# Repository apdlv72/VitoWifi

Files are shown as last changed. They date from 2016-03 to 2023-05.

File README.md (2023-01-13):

Update 2023-01-11: Added support to pull desired ventilation level from external web site. Added support for sending notification via web API.  Fixed also some bugs.

Arduino sketch for a ESP-8266 WiFi micro controller to control a Vitovent 300 
home ventilation unit via a OpenTherm Gateway and a WiFi connection.

Vitovent is a registered trademark held by the German manufacturer Viessman.
It is a device used for automatic home ventilation with heat recovery.
For more detail please check the manufacturer's page:
http://www.viessmann.de/de/wohngebaeude/wohnungslueftung/zentrale_wohnungslueftung/vitovent-300-w.html

The actual ventilation unit is communicating with the remote controller via a 
2-wire cable connection using the OpenTherm protocol. 
Since the controller has only very limited capabilities, I wanted more control 
over when to start/stop ventilation and at what throughput.
In particular, I wanted to adjust the fan stage automatically depending on the
air and weather conditions. For example, I want the fan to run at max speed only
if this is really necessary (CO2 level too high), wanted to stop it at summer 
time when it's already hot outside and still cool inside, run at higher levels
during the cool night hours or after a rain shower.    

The ESP does not communicate with the Vitovent directly. It needs a gateway that  
converts the voltage levels and protocol used between the controller and the unit
on the one hand and the ESP on the other hand via UART (RS232 with 3.3V voltage)
This gateway was designed by Schelte Bron (see http://otgw.tclcode.com) and is
called OTGW (OpenTherm Gateway).

The general setup looks as follows:

<pre>
[Controller] <-----OT-----> [OTGW] <------OT------> [VitoVent]
                               ^
                               | RS232 (* see WARNING2 below)      
                               |     
[WebBrowser] <----WiFi----> [ESP8666]  
</pre>

Using this sketch will allow you to collect the information that was intercepted by 
OTGW and to display it on any (mobile oder desktop) browser.
 
It will also allow to control the ventilation level resp. start/stop ventilation.
Provided you create a rule for this on your router, you could even control the unit
over the internet.

Besides reading and parsing the messages from the OTGW, the sketch implements also
reading the temperature of some DS18B290 temperature sensors attached to GPIO2 of the
ESP8266. This allows to monitor the temperature at the four air connections of the
unit (supply in/outlet & exhaust in/outlet). Although the VitoVent provides its own
measures for this, it does so however only on the inlet side (at least mine).  
 
<b>WARNING 1:</b> There is absolutely no access control implemented. Doing so means that 
virtually everybody can control your unit. You should assert a security policy 
by some other means then, e.g. with a web server that implements access restrictions
before proxying the request to the ESP running this sketch.

<b>WARNING 2:</b> The ESP is powered by 3.3V while the OTGW needs 5V. Also the logic levels
on the I/O pins are 0/3.3V and 0/5V. While some people say that the ESP is not 5V
tolerant, some say that this is a myth since the datasheets states that there is some
electronics to protect agains over voltage.
It's up to you to find out who is right and to risk to brick a ESP. 
For safe operation it is recommended to use a logic level shifter such as he AN10441 or 
PCA9306 or at least to use a voltage divider on the EPS's RX pin.

Note that the cables need to be crossed thus connecting Rx on the ESP side to Tx on the
gateway and vice versa.

GPIO0 - which is used during flashing the ESP (must be pulled to ground) - can be
connected to a LED and a resistor (approx. 200-30Ohms) towards Vcc (3.3V). 
It will be used as a heart beat to indicate this sketch is still operating and also
show the current fan speed by flashing at different speeds.   

GPIO2 can be used to attach one ore more temperature sensors. A 4k7 pullup must be
used between this pin and Vcc in this case:

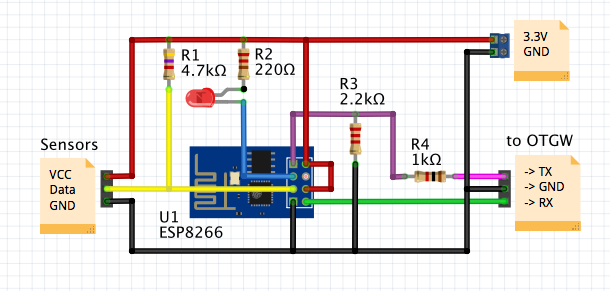
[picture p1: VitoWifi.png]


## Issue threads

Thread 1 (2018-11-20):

DIffferent Versions of Vitovent 300W

challo2018, 2018-11-20:
Hi, can someone give me datails about exact version of working 300w?
It seems that OpenTherm is not activated on mine :-(
Is it necessary to have the control panel connected on OT? Actually i have no control panel connected due the vitovent is connected to my Vitocal via Modbus.
Can you also give me hint (Art. Number etc) of your controll panel if this is necessary. Is it LB1?

Thanks!
BR Fabian

apdlv72, 2018-11-20:
Hi Fabian.

I am German, feel free to reply in German if you are capable of speaking it.

I have no idea what different versions Viessman produced in the past and I found
by incident that mine (built 2009) is OpenTherm-enabled when I opened the
remote control and stumbled over a small “OT” printed next to the screw terminator
that connects to the 2-wire line.

Also, I don't know the exact manufacturer code but it’s the same depicted here:
https://www.heizsystemshop.de/lueftungen/fernbedienung-vitovent-300.html

I don’t know if it’s possible to connect this kind of controller to YOUR Vitovent,
but I am wondering why you would like to do so???

Actually the VitoWifi project aims at connecting “somehow” to a Vitovent which
does not provide such connectivity out of the box.

When your’s has Modus already … why don’t you use that?
What exactly are you trying to achieve?

Greetings from Cologne.

Artur Pogoda de la Vega
apdlv72@gmail.com

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

challo2018, 2018-11-20:
Hi Artur,
danke für deine Antwort. Meine Vitovent 300W ist aus dem Jahr 2017.
Von meinem Heizungsbauer wurde empfohlen diese über Modbus mit der Steuerung meiner Wärmepumpe zu verbinden. Jetzt kann ich an der Wärmepumpe auch die Lüftung steuern. Eine Einbindung in mein Loxone smarthome ist allerdings nicht möglich. werder bei der wärmepumpe noch bei der lüftung. für die Wärmepume gibt es für ca. 1000€ ein KNX gateway. Damit kann allerdings nicht auf die Lüftung zugegriffen werden. Ich habe ein OTGW hier liegen und die Platine hat auch weiterhin diesen 2 Draht anschluss. Allerdings ist dieser nicht mehr mit OT sondern mit "Bedienteil (2-poliger Stecker, Adern vertauschbar,X1.1/X1.2) beschrieben. Ich habe dieses Bedienteil leider nicht. Wenn ich dort den OTGW anschließe bekomme ich keine Daten. Für eine direkte Ansteuerung über Modbus habe ich bisher noch keine Dokumentation oder ähnlich gefunden.
"

apdlv72, 2018-11-20:
Hi Fabian.

Deutsch macht die Kommunikation deutlich einfacher :-)

Kannst du Mal ein Bild der Platine schicken? Ich bin ein wenig verwirrt,
welche du meinst. Die des otgw? Oder des beckenteils? Welches du ja gar
nicht hast?

Wenn deine Wärmepumpe Modbus kann aber du noch nicht rausgefunden hast, wie
genau deine Lüftung per Modbus abgesprochen werden kann, nutzt dir
vermutlich mein Projekt wenig.

Modbus würde ich in jedem Fall vorziehen. Otgw ist nur eine Notlösung um
eine Lüftung einzubinden, die nichts anderes spricht.

Ob da trotzdem ein Signal anliegt oder nicht... Wie hast du das
rausgefunden? Weisst du, dass dein otgw funktioniert? Hast du es selbst
gelötet?

Verrat mir Mal, wo du wohnst. Ich komme aus Köln. Evtl. können wir Mal mein
definitiv funktionierendes otgw bei dir anschließen?

Gruss, Artur

Am Di., 20. Nov. 2018, 15:44 hat Artur Pogoda de la Vega <apdlv72@gmail.com>
geschrieben:

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

apdlv72, 2018-11-22:
Hallo Fabian.

Bei näherem Nachdenken ist mir klar geworden, dass Du gar keine Daten sehen KANNST,
wenn Du nur das OTGW an Deine Lueftung haengst aus folgendem Grund:

Das OTGW haengt ja im Prinzip nur zwischen dem Bedienter und dem Lueftungsgeraet und
schiebt die Befehle nur hin und her.

Die Lueftung (hier Slave) schickt von sich aus überhaupt keine Kommandos auf die Leitung sondern
beantwortet im Prinzip nur die Kommandos vom Bedienteil (hier Master).
Das einzige, was das OTGW in diesem Szenario fuer dich tun kann, ist es, den Befehl vom Master,
der die Lueftungsstufe bestimmt, so zu ersetzen, bevor es ihn weitergibt, dass die eingestellte
Luefterstufe durch eine andere ersetzt wird, die Du gerne stattdessen hättest und die Du von aussen
im OTGW setzt.

Wenn Du mir Dein OTGW schicktest, koennte ich zwar ausprobieren, ob es prinzipiell funktioniert,
damit ware Dir aber nicht weitergeholfen, weil es von sich aus nicht das Bedienteil ersetzt,
sondern wie oben beschrien nur man-in-the-middle spielt.

Da Du eine NodeMCU besitzt und anscheinend des Loetens mächtig bist, könntest Du was anderes
probieren. Ich stehe im Kontakt mit einem Nutzer, der ein ähnliches Ziel hat. Er besitzt eine Vitivent,
die definitiv OpenTherm spricht, aber er hat auch kein Bedienteil und möchte es durch einen ESP8266
ersetzen.
Er hat auch schon das Beispiel “master” aus folgendem Projekt an seiner Vitovent erfolgreich ausprobiert:
https://github.com/jpraus/arduino-opentherm/tree/master/examples/master

Allerdings nur mit einem Arduino, d.h. ohne Wifi-Anbindung.
Leider lässt sich das Beispiel nicht mit dem ESP kompilieren, weil die Initialisierung der Interrupt-Routinen
da ganz anders funktioniert. Weil er damit keine Erfahrung hatte, hat er ich um Hilfe gebeten.

Es gibt ein anderes Projekt, das  auf dem ESP kompiliert (sogar auf dem ESP-32), allerdings kann/konnte
das nicht eine Lueftung steuern, sondern nur den Thermostat fuer einen Boiler simulieren:
https://github.com/ihormelnyk/opentherm_library <https://github.com/ihormelnyk/opentherm_library>

Da ich es viel einfacher fand, Beil letzterem die nötigen Befehle/Funktionen hinzuzufügen, als das erste
Projekt zu Portieren, habe ich das getan:
https://github.com/apdlv72/opentherm_library/tree/master/examples/VentilationMaster <https://github.com/apdlv72/opentherm_library>

Allerdings ist es gänzlich ungetestet. Ich habe nur das Original-Projekt geformt und erweitert.
Im Prinzip werden die nötigen Kommandos geschickt, allerdings wird vermutlich noch Feinarbeit nötig sein.
Ich kann das leider noch nicht testen, weil ich noch auf die Interface-Platine warte. Sie ist auf dem Postweg
aus der Ukraine und das kann leider etwas dauern.
(http://ihormelnyk.com/opentherm_adapter <http://ihormelnyk.com/opentherm_adapter>)

Im Prinzip muesstest Du diese aber gar nicht haben, um zu Testen, ob deine Lueftung Kommandos
schickt oder nicht. Die Platine implementiert im Prinzip nur den Lueftings-seitigen Teil des OTGW, d.h.
kann Kommandos schickt und empfangen, nicht aber zum Bedienteil.

Wenn Du den PIC auf dem OTGW herausziehst (ist hoffentlich gesuckelt?), könntest Du Deine NodeMCU
an den entsprechenden Stellen per Dupont-Kabel einstecken und mit meinem Beispiel versuchen,
Bedienteil zu spielen, um zu sehen, ob Die Kommandos ueberhaupt beantwortet werden.
Vorausgesetzt, Du hast Dich nicht verlötet beim OTGW und Deine Lueftung spricht OT, muesstest die
im Prinzip schon Antworten sehen koennen, ohne dass Du irgendwas neu anschaffen musst.

Falls das funktioniert, kannst Du entweder das OTGW, was Du eh schon gekauft hast, statt mit dem
PIC mit dem NodeMCU betreiben oder Du kannst Dir den o.g. Opentherm Adapter bestellen oder selbst
loeten. Das sind nur wenige billige Bauteile, die schnell auf einer Lochrasterplatine zusammengelötet sind.
Da ich momentan zu wenig Zeit habe, hab ich mir das bequemerweise bei Ihor bestellt.

VG
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
arnolde, 2019-01-19:
Hallo, sorry wenn ich hier so reinplatze ;-) ich hab gerade diese Woche meine ESP mittels Ihor's Library (manuell um einige Lüftungs-Parameter ergänzt) und Ihor's OT Interface geschafft, meine WOLF CWL 300 (baugleich Vitovent) anzusteuern und auszulesen. Momentan kann ich die Lüfterstufen 0,1,2,3 schalten oder auch die rel.lüfterleistung von 20%-95% stufenlos einstellen.

Was ich noch nicht geschafft hab ist die Filteranzeige auszulesen (wobei ich jetzt hier gelesen hab daß das TSP (Id 89) Nummer 0x17 sein soll, 1 ist offenbar "filter ok", mal sehen was meiner grad sagt, bei dem ist grad die Filteranzeige an. Ausserdem den Bypass noch ansteuern (da ich einen Erdwärmetauscher hab, will ich den Bypass im Sommer aus haben um kühle Luft reinzuziehen). Und perfekt wäre wenn ich den Lüfter auch unterhalb 20% noch einstellen könnte, damit ich im Winter bei trockener Luft eine noch minimalere Lüftung haben kann.

viele Grüße,
Ethan

arnolde, 2019-01-19:
Seltsam, ich hab grad alle 64 TSP's ausgelesen und erhalte für 0,2,4: 0x64, 0x96 und 0x2c - das passt aber nicht zu den tatsächlichen Ergebnissen wenn ich die Stufen 1/2/3 aktiviere dann sind die ausgelesenen Drehzahlen: 0x24, 0x39 und 0x5f.

madmax75, 2020-04-29:
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

Hallo Ethan,
ich betreibe ebenfalls eine Wolf CWL 300 und würde diese gerne per OTGW auslesen. Ich habe ein Gateway mit NodeMCU hier bei mir liegen und habe versucht mit dieser die KWL anzubinden. Leider vergeblich. Gibt es eine Anleitung wie die genaue Vorgehensweise ist um die Verbindung herzustellen?

apdlv72, 2020-04-30:
Hallo madmax75!

Was genau hast du denn versucht und was hat nicht geklappt? Da du das Gateway ja schon fertig da liegen hast (Bausatz selbst zusammen gelötet oder fertig gekauft?), sollte das Anschließen selbst ja relativ unproblematisch sein: Kabel zur Lüftung an die eine klemme, Kabel zum Controller an die andere.

Danach muss vermutlich noch auf den PIC des otgw die aktuelle Software aufgespielt werden und anschließend auf dem mcu deine eigene Lösung oder z.B. mein vitowifi, um mit dem otgw zu kommunizieren, um den aktuellen Status verfügbar (WLAN) zu machen oder die Lüfterstufen zu beeinflussen.

VG
Artur

madmax75, 2020-05-03:
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

Hallo Artur,

> Danach muss vermutlich noch auf den PIC des otgw die aktuelle Software aufgespielt werden und anschließend auf dem mcu deine eigene Lösung oder z.B. mein vitowifi, um mit dem otgw zu kommunizieren, um den aktuellen Status verfügbar (WLAN) zu machen oder die Lüfterstufen zu beeinflussen.

Ganau hier komme ich nicht weiter. Wie bekomme ich die die aktuelle Software auf das Gateway und welche muss ich genau nehmen?
Stehe da gerade total auf dem Schlauch.

VG
Andre

madmax75, 2020-05-09:
Hallo Artur,
ich habe jetzt erfolgreich die PIC und die nodemcu flashen können und bekomme nun auch die Webseite angezeigt.
Ich habe nun noch keine Info gefunden wie ich meine FB mit dem OTGW verbinden muss(welche Klemmbelegung).

Gruss
André

gzin, 2021-03-29:
Hallo Artur!
Ich habe auch eine Wolf CWL 300 und das Gateway von Shelte Brom. Wenn ich den Ethernet-Aufsatz aufstecke, dann kann ich per serieller (Netzwerk-)Verbindung schon wunderbar mitlesen: nach dem Befehl "GW=1" schickt er zyklisch ein paar Befehle hin und bekommt Antwort. Leider wechselt die CWL immer zwischen 0 ("ferngesteuert") und 1 ("Wahlschalter"). Wenn ich dann den Befehl "GW=0" sende, ist die Anlage wieder dauerhaft im Wahlschalter-Modus. (eine inkludierte Fernsteuerung über OpenTherm habe ich nicht)
Spiele ich die Software von dir auf den NodeMCU (auf derselben Platine wie der PIC; statt dem Ethernet-Modul), dann beobachte ich dieses zyklische Umschalten zwischen 0 und 1 ebenfalls. Also nehme ich an, dass die Ansteuerung funktioniert (zumindest "GW=1").
Ich habe noch vom Betrieb über das Arduino-Terminal gesehen, dass da Befehle wie ZZ=r oder oder ZZ=wwww gesendet werden. Sollte die Firmware das können? Wenn ich mir die Befehle so ansehe, steht da nichts von "ZZ" drinnen:
http://otgw.tclcode.com/firmware.html#configuration
Verwende ich die falsche Firmware? (ich habe die aktuellste eingespielt) Ist der Befehl "ZZ" bei der neuen Firmware raus geflogen?

Alterntiv habe ich mir das Modul aus der Ukraine (http://ihormelnyk.com/opentherm_adapter) samt Adapter für Mini-D1 (8266) bestellt und bekommen. Hier komme ich aber auch nicht weiter, weil ich noch beim Programmieren hänge.

apdlv72, 2023-01-11:
No action anymore

apdlv72, 2023-01-11:
Closing

gzin, 2023-01-11:
Inzwischen läuft das Modul mit dem D1-Mini recht gut, ich kann die Lüftungsstärke steuern und auch alle Register auslesen.

Was noch nicht klappt ist die Steuerung des Bypasses und das Auslesen der Filter-Alarms. Hat da jemand eine Idee?

Gruß
Günther

Closed 2023-01-11.

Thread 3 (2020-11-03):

cant connect to ap

crazypaddo, 2020-11-03:
hello sir, i have a brink wtw ventilation unit.(same as vitovent)
i have 2 otgw interfaces,
i first used off 1 otgw only the boiler part to connect to a arduino mega as a master with the opentherm library to send commands to  the wtw unit.
this works because i can turn the unit on and off and set the relative ventilation value.
So data is flowing between the master and slave.
now i have programmed a nodemcu v3 with your project. so far so good.
i see the ssid apear when i want to connect to the network http://192.168.4.1 and i see something about tokken created in the debug terminal.
i open my webbrowser and go to http://192.168.4.1 type VitoWifi and password 12345678 and hit connect.
but when i look at the debug terminal from the esp i see error 4 and the page counts down and times out?
but the data from my arduino mega master gets true the gateway because the ventilation units stays in opentherm modus
and when i change the send data id in the master the unit changes the value.(speeds up / slows down ventilation motors).
but i am not an expert in programming and cant seem to figure out whats the problem.
could it be due to me turning aldataids on? because i got some errors in arduino while compiling about dupicated case entrys?
i commented the out,and it compiled without errors. but maybee i broke something wyle doing this.
i hope you an guide me in the write direction. so i can save a lot off monney on my heating bill that my heat provider want from me to heat a small appartment.
regards marco van oort

apdlv72, 2023-01-11:
No action. Closing

apdlv72, 2023-01-11:
Close

Closed 2023-01-11.

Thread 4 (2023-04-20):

Any known solution for connecting via modbus?

thilasx, 2023-04-20:
Hey there!
Thanks for sharing your solution for the vitovent with OT protocol.
I'd like to ask if you know a solution for reading the sensors and configuring the vent via modbus?
I searched the net yesterday but was only able to find that viessmann is most likely buying their vent solutions from another manufacturer called brink and that some people were able to use a modbus adapter but weren't able to connect successfully.
Therefore, because you mentioned in another issue that you would prefer modbus, I thought you might know a way.

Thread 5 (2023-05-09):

Fehlermeldung beim Kompilieren

madmax75, 2023-05-09:
Hi @apdlv72,
ich wollte die aktuelle Version auf meine nodemcu per Arduino IDE aufspielen, erhalte jedoch die folgende Fehlermeldung:

In file included from /Users/andre/Documents/Arduino/ESP_VitoWifi/ESP_VitoWifi.ino:175:
/Users/andre/Documents/Arduino/ESP_VitoWifi/OTMessage.h: In static member function 'static String OTMessage::msgTypeToStr(uint8_t)':
/Users/andre/Documents/Arduino/ESP_VitoWifi/OTMessage.h:48:5: error: control reaches end of non-void function [-Werror=return-type]
   48 |     }
      |     ^
cc1plus: some warnings being treated as errors

exit status 1

Compilation error: control reaches end of non-void function [-Werror=return-type]

apdlv72, 2023-05-10:
Hi.

Welche Arduino version? Ich habe das seit Dezember nicht mehr gebaut. Da
fehlt wohl ein Return in der Funktion wie zb return "" am Ende der
Funktion.

Falls du es selbst hinbekommst, mache gerne einen pull request. Ansonsten
melde dich nochmal. Ist bestimmt kein biggie.

Gruß,
Artur

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

madmax75, 2023-05-11:
Hi Artur,
ich habe es mit Arduono IDE 2.1.0 versucht und es leider mit deiner Anweisung nicht hinbekommen. Könntest du dir das netterweise mal anschauen?
LG André

madmax75, 2023-06-04:
> Hi Artur,
> ich habe es mit Arduono IDE 2.1.0 versucht und es leider mit deiner Anweisung nicht hinbekommen. Könntest du dir das netterweise mal anschauen?
> LG André

apdlv72, 2023-06-05:
Hall Andre.
Ich verstehe nicht, wie der jetztige Stand ist. Compiliert es jetzt bei Dir oder immer noch nicht?
Habe gesehen, dass Du den Request geschlossen und sofort wieder geoeffnet hast.
VG, Artur

madmax75, 2023-06-05:
Hallo @apdlv72,
leider erhalte ich beim kompilieren die oben genannte Fehlermeldung. Hatte aus Versehen den Request geschlossen.
VG
Andre

apdlv72, 2023-06-07:
Hallo Andre!
Welche Fehlermeldung? Die urspruengliche? (control reaches end of non-void function)
Hast Du denn neu gepullt nachdem ich das letzten Monat gefixt hatte?
Der aktuelle Code sieht so aus - siehe unten.
In der Zeile 48 ist jetzt vorher fehlende der Default-Rueckgabewert, ueber den sich der Compiler beschwert hat.
Wie bereits geschrieben, habe ich das _auch_ mit der Version 2.1.0. der IDE erfolgreich kompilieren koennen.
VG, Artur

37 static String msgTypeToStr(uint8_t t) {
38      switch(t) {
39        case MT_READ_DATA:    return "READ_DATA";
40        case MT_WRITE_DATA:   return "WRITE_DATA";
41        case MT_INVALID_DATA: return "INVALID_DATA";
42        case MT_RESERVED:     return "RESERVED";
43        case MT_READ_ACK:     return "READ_ACK";
44        case MT_WRITE_ACK:    return "WRITE_ACK";
45        case MT_DATA_INVALID: return "DATA_INVALID";
46        case MT_UNKN_DATAID:  return "UNKN_DATAID";
47      }
48      return "UNKNOWN";
49    }

madmax75, 2023-06-18:
Hi @apdlv72,
ich habe es nun am Laufen. Besten Dank.
Wie kann ich nach dem Setup den Access Point Modus "AP_VitoWifi" abschalten, sodass dieser nicht mehr sichtbar ist?

Gruß
Andre

apdlv72, 2023-07-03:
Hi @madmax75 !

Versuche es mal in folgender Zeile
https://github.com/apdlv72/VitoWifi/blob/master/ESP_VitoWifi.ino#L885
EE.accessPoint.used = 0 zu setzten.
Das ist aber ohne Gewaehr. Ich habe bei mir den AP Modus immer aktiviert,
um z.B. bei einem Router-Wechsel das Passwort aendern zu koennen ohne
dass ich den ESP ausbauen muss.

Du kannst auch in diese Zeile:
https://github.com/apdlv72/VitoWifi/blob/master/ESP_VitoWifi.ino#L1775
Fest den AP ausschalten mit:
WiFi.mode(WIFI_STA);

VG,
Artur

Closed 2023-08-17.

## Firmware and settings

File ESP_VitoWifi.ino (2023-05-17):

// Copy secrets.h to secrets_priv.h, same for index.html.h and comment in to 
// activate your own versions of this file. Add both files to .gitignore!!!
#define WITH_OWN_SECRETS

#ifdef WITH_OWN_SECRETS
#include "secrets_priv.h"
#else
#include "secrets.h"
#endif

/**
   Arduino sketch for a ESP-8266 WiFi micro controller to control a Vitovent 300
   home ventilation unit via a OpenTherm Gateway and a WiFi connection.
   See https://github.com/apdlv72/VitoWifi or README.md
   @author: apdlv72@gmail.com
*/

// Uncomment WITH_DALLAS_TEMP_SENSORS to enable support for DS18B290 temperature sensors connected on PIN_SENSOR.
// MAX_NUM_SENSORS defines the maximum number of sensors connected.
// Since this sketch is for a home ventilation system, actually 4 would be sufficient for inlet/outlet air supply
// and inlet/outlet exhaust. However, defining 8 here lets us add even more e.g. for monitoring the room temperature(s)
// in your basement and/or living room, monitoring the temperature inside the OTGW device and so forth.
// Every sensor requires just 2 bytes in RAM, so a large value is not too critical.
#define WITH_DALLAS_TEMP_SENSORS

#define MAX_NUM_SENSORS 6

// Uncomment to support a pin test on http://192.168.4.1/pintest?p=0.
// When called, the mode of the respective pin "p" will be set to OUTPUT and value toogled between hi/low a couple of times.
// This is useful to find out which pin number is assigned to what pin. Be careful with pins used by the ESP.
// Check https://github.com/esp8266/Arduino/issues/1219 for more details.
//#define WITH_PIN_TEST

// Uncomment to enable ID to text translation of all known OpenTherm data IDs.
// This cause a considerable overhead in RAM usage and is not enable by default since it is not used for normal operation.
// However, should you use this sketch as a starting point to control anything else than a VitoVent 300, you might enable
// this to learn what your devices are talking to eachother.
//#define WITH_ALL_DATAIDS

// enable OTA (over the air programming)
//#define WITH_OTA

// Enable serial debug functions
//#define WITH_DEBUG_SERIAL

// Enable sending debug messages on UDP port
#define WITH_DEBUG_UDP
#define UDP_PORT 4220

// Enable sending continuous stream of OT messages received on /dbg/tailf
// #define WITH_TAILF

// Enable a help page on http://192.168.4.1/help
//#define WITH_USAGE_HELP

// Enable html page to setup the device via browser.
//#define WITH_WEB_SETUP

// Enable upating ventilation level from an external web page on a regular basis.
// Also requied to send alerts using a web API.
#define WITH_WEB_CALLS

// Enable adding invalid lines (commands) being handles as errors
#define WITH_INVALID_LINES_AS_ERRORS false

const char DEFAULT_START_SSID[] = "AP_VitoWifi";

// Initial password used to connect to it and set up networking.
// The device will normally show up as SSID "http://192.168.4.1"
// Connect to this network using the intial password and navigate your
// browser to the above URL.
#define DEFAULT_PSK  "12345678"

#define HTTP_LISTEN_PORT 80

/****************************************/

#include <errno.h>
#include <EEPROM.h>

#ifdef ESP8266
#include <ESP8266WiFi.h>
#include <ESP8266WebServer.h>
#elif ESP32
#include <WiFi.h>
#include <WiFiClient.h>
#include <WebServer.h>
#else
#error Unsupported platform
#endif

#ifdef WITH_OTA
#include <ArduinoOTA.h>
#endif

#include <WiFiUdp.h>
#ifdef WITH_WEB_CALLS
#include <UrlEncode.h>
#endif

#ifdef WITH_DALLAS_TEMP_SENSORS
#include <OneWire.h>
#include <DallasTemperature.h>
#endif

// Using a copy of "easy EEPROM" library since needed to modify for ESP
// to cope with watchdog timer resets (https://github.com/apdlv72/eEEPROM)
//#include "eEEPROM.h"

const String buildNo   = __DATE__ " " __TIME__;

#define LED_HEART 	  0 // heartbeat 
#define LED_ONBOARD   2 // blue onboard LED / temp. sensors

#define LEVEL_NOOVER -1 // do not overrride (monitor mode)
#define LEVEL_OFF     0 // standby, ventilation off
#define LEVEL_LOW     1 // "reduced" mode (27% for mine ... may vary)
#define LEVEL_NORM    2 // "normal"  mode (55% for mine) 
#define LEVEL_HIGH    3 // "party"   mode (100%)

// result codes of onOTMessage
#define RC_OK         0	// message handled
#define RC_INV_LENGTH 1 // invalid message length (not Sxxxxxxxx)
#define RC_INV_FORMAT 2 // xxxxxxxx was not a parsable hex value
#define RC_INV_SOURCE 3 // S is not a known source (T,B.R,A)
#define RC_UNEXP_T    4 // unexpected message from T(hermostat)/controller/master
#define RC_UNEXP_B    5 // unexpected message from B(oiler)/ventilation/slave
#define RC_UNEXP_R    6 // unexpected request (sent by OTG in favor of master)
#define RC_UNEXP_A    7 // unexpected answer  (sent by OTG in favor of slave)
#define RC_UNEXP_O    8 // unexpected message from unknown source (should never occur) 

#define CT_TEXT_PLAIN  "text/plain"
#define CT_TEXT_HTML   "text/html"
#define CT_APPL_JSON   "application/json"

// Context type sent along with content stored in PROGMEM:
const char PGM_CT_TEXT_HTML[] PROGMEM = "text/html";
const char PGM_CT_APPL_JSON[] PROGMEM = "application/json";

#ifdef WITH_OWN_SECRETS
#pragma message "index_priv.h is active"
const char HTML_INDEX[] PROGMEM =
#include "index_priv.html.h"
  // The following line makes buildNo accessible for javascript:
  "<script>var buildNo = '" __DATE__ " " __TIME__ "';</script>";
;
#else
const char HTML_INDEX[] PROGMEM =
#include "index.html.h"
  // The following line makes buildNo accessible for javascript:
  "<script>var buildNo = '" __DATE__ " " __TIME__ "';</script>";
;
#endif

#ifdef WITH_WEB_SETUP
const char HTML_SETUP[] PROGMEM =
#include "setup.html.h"
  ;
#endif

#ifdef WITH_ICONS
const char MANIFEST_JSON[] PROGMEM =
#include "manifest.json.h"
  ;

const char FAVICON_ICO[] PROGMEM =
#include "favicon.ico.h"
  ;

const char FAN_PNG[] PROGMEM =
#include "fan.png.h"
  ;
#endif  

// Conveniently zero-terminates a C-string.
#define TZERO(STR) { (STR)[sizeof((STR))-1] = 0; }

#include "OTMessage.h"

typedef struct {
  // Use signed 16 bits to allow -1 to indicate that
  // value was not yet assigned.
  int16_t hi;
  int16_t lo;
} Value;

// Global status
struct {
  struct {
    long serial; // time of last message via serial line
#ifdef WITH_DEBUG_SERIAL
    struct {
      long fed;		// via URL /feedmsg?msg=...&feed=1
      long debug; 	// via URL /feedmsg?msg=... (parsed only, not fed)
    } wifi;
#endif
  } lastMsg;         // time (millis()) when last message was received

  int16_t  ventSetpoint; 	   // as set by controller
  int16_t  ventOverride; 	   // as overridden by OTGW (sent to slave instead of ventSetpoint)
  int16_t  ventWeb;          // received from external web resource/page (see web_update.h)
  int16_t  ventAcknowledged; // by the slave, sent to OTGW
  unsigned long lastAcknChange;

  int16_t  ventReported;     // from OTGW to controller, pretending level is as requested (ventSetpoint)
  int16_t  ventRelative; 	   // as reported by ventilation
  int16_t  tempSupply;  	   // milli Celsius (inlet)
  int16_t  tempExhaust;  	   // milli Celsius (inlet)
  int16_t  tsps[64];  	 	   // transparent slave parameters

  struct {
    Value master;
    Value slave;
  }        version;			// values for DI_*_PROD_VERS

  Value    status;
  Value    faultFlagsCode;
  Value    configMemberId;
  Value    masterConfig;
  Value    remoteParamFlags;

  struct {
    long serial;	// total number of messages received on serial line

    struct {
      long fed; 	// via /feedmsg?feed=1...
      long debug; 	// (parsed only, not fed)
    }    wifi;

    // number of invalid messages received
    struct {
      long length;		// invalid length
      long format;		// invalid line (pasing failed)
      long source;		// invalid source (not T,B,R,A)
    } invalid;

    // expected messages of various types
    struct {
      long T; long B; long R; long A;
      long otgw; // otgw message response e.g. "GW: 1" replied on "GW=1"
    } expected;

    // unexpected messages of various types
    struct {
      long T; long B; long R; long A; long zero;
    } unexpected;

  } messages; // number of messages received

  unsigned long timeAdj = 0;
  String scriptVersion;
  String scriptName;
  String filterAction;
  String cartridgeAction;

#ifdef WITH_DALLAS_TEMP_SENSORS
  int sensorsFound;
  long lastMeasure;
  int16_t extraTemps[MAX_NUM_SENSORS];
#endif

} state;

// Health monitoring and alert/report book keeping
struct {
  // time when requested and acknowleged override started to differ
  unsigned long ventDiffStarted = 0;
  // time when last report sent that there is a difference
  unsigned long lastDiffReported = 0;
  // time we sent a recovery message (device responsive again)
  unsigned long lastRecoveryReported = 0;
  // time of last OTGW reset attempt
  unsigned long lastGWReset = 0 ;
  // time of when GW reset was reported
  unsigned long lastGWResetReported = 0;

  boolean isResponsive  = true;
  boolean wasResponsive = true;

  // initial memory
  long initalFree = -1;

  // 1 hour before millis() will roll over
  unsigned long rebootTime = 4294967296 - 3600 * 1000;

  boolean startAnnounced = false;
  boolean rebootAnnounced = false;

  unsigned long lastWebCheck = 0;
  unsigned long lastWebCheckError = 0;

  unsigned long webFailCount = 0;
  unsigned long postOkCount = 0;

  String lastRebootDetails = "";

  long loopIterations = 0;
} health;


#define WEB_CHECK_INTERVAL (20*60*1000) // 20 minutes

// Credentials used to 1. set up ESP8266 as an access point and 2. define WiFI network to connect to.
typedef struct {
  uint8_t used;
  char    ssid[32 + 1];
  char    psk[32 + 1];
} Credentials;

// I'm from cologne ;)
const uint16_t MAGIC = 0x4712
;

// Everything that goes to EEPROM
struct {
  // Detect if first time setup of EEPROM was done.
  uint16_t  magic;
  boolean 	configured;
  // Start ESP in access point mode?
  Credentials accessPoint;
  // Network to connect to
  Credentials homeNetwork;
  // Count incremented on every reboot to enable monitoring of device crashes.
  uint32_t reboots;
  char     rebootDetails[128];
} EE;

// User committed first time setup (e.g. AP, network) and it was saved permanently.
boolean configured = false;

// A random token used during setup to authenticate committer.
char configToken[10 + 1];

// Time at which an attempt to connect to a network will be considered expired during setup procedure.
long connectAttemptExpires = -1;

// Remember whether temperatures have been already requested for the first time.
boolean temperaturesRequested = false;

// After setup, a reboot is necessary. However, cannot do this while handling client request,
// because this will abort the connection. Instead of this, finish sending the reponse to the
// client and schedule a reboot after millis() will exceed this value.
long rebootScheduledAfterSetup = -1;

// A string to hold incoming serial data from OTGW.
String inputString = "";
// wWhether the string is complete.
boolean stringComplete = false;

// set in setup()
unsigned long stopUdpLoggingAfter = 0;

#ifdef ESP8266
ESP8266WebServer server(HTTP_LISTEN_PORT);
#elif ESP32
WebServer server(HTTP_LISTEN_PORT);
#endif

/***************************************************************

   Heart beat LED

*/

boolean led_lit = false;
volatile boolean led_blink = false;
int timer_value = 250000;

//void ICACHE_RAM_ATTR timerRoutine() {
void IRAM_ATTR timerRoutine() {
  if (led_blink) {
    led_lit = (millis() / 50) % 2;
    digitalWrite(LED_HEART, led_lit ? LOW : HIGH);
  }
  timer1_write(timer_value);
}

void ledToggle() {
  led_lit = !led_lit;
  digitalWrite(LED_HEART, led_lit ? LOW : HIGH);
}

void ledFlash(int ms) {
  ledToggle();
  delay(ms);
  ledToggle();
}

/***************************************************************

   Dallas temperature sensors support

*/

#ifdef WITH_DALLAS_TEMP_SENSORS

// Data wire is plugged into port 2 on the Arduino
#define ONE_WIRE_BUS 2 // GPIO2
#define TEMPERATURE_PRECISION 9


// Setup a oneWire instance to communicate with any OneWire devices (not just Maxim/Dallas temperature ICs)
OneWire oneWire(ONE_WIRE_BUS);

// Pass our oneWire reference to Dallas Temperature.
DallasTemperature sensors(&oneWire);

#endif // WITH_DALLAS_TEMP_SENSORS

/***************************************************************
   Debug support
*/

#define DBG_OFF 0
#define DBG_ON  1
#define DBG_UDP 2

#if defined(WITH_DEBUG_SERIAL)

int DEBUG_LEVEL = DBG_ON;
void dbg(String s)         {
  if (DBG_OFF < DEBUG_LEVEL) {
    Serial.print("");
    Serial.print(s);
  }
}
void dbgln(String s)       {
  if (DBG_OFF < DEBUG_LEVEL) {
    Serial.print("");
    Serial.println(s);
  }
}
void dbg(const char * s)   {
  if (DBG_OFF < DEBUG_LEVEL) {
    Serial.print("");
    Serial.print(s);
  }
}
void dbgln(const char * s) {
  if (DBG_OFF < DEBUG_LEVEL) {
    Serial.print("");
    Serial.println(s);
  }
}
void dbg(int i)            {
  if (DBG_OFF < DEBUG_LEVEL) {
    Serial.print("");
    Serial.print(i);
  }
}
void dbgln(int i)          {
  if (DBG_OFF < DEBUG_LEVEL) {
    Serial.print("");
    Serial.println(i);
  }
}

#elif defined(WITH_DEBUG_UDP)

WiFiUDP UDP;
boolean doLogUDP = false;

void logUDP(String msg) {
  if (doLogUDP) {
    UDP.beginPacket("255.255.255.255", UDP_PORT);
    UDP.print("  ");
    UDP.print(msg);
    UDP.endPacket();
  }
}

int DEBUG_LEVEL = DBG_OFF;
void dbg(String s)         {
  logUDP(s);
}
void dbgln(String s)       {
  logUDP(s);
}
void dbg(const char * s)   {
  logUDP(s);
}
void dbgln(const char * s) {
  logUDP(s);
}
void dbg(int i)            {
  logUDP(String(i));
}
void dbgln(int i)          {
  logUDP(String(i));
}

#else

int DEBUG_LEVEL = DBG_OFF;
#define dbg(WHATEVER) {}
#define dbgln(WHATEVER) {}

#endif

long leastHeap  = -1;
long maxStack = -1;

void checkMemory() {
  long curr = ESP.getFreeHeap();
  if (curr<leastHeap || leastHeap<0) {
    leastHeap = curr;
  }
  curr = getStackSize();
  if (curr>maxStack || maxStack<0) {
    maxStack = curr;
  }  
}


#ifdef WITH_WEB_CALLS
#include "web_update.h"
boolean doSendAlerts = true;
#endif


/***************************************************************

   OpenTherm message parsing

*/

int onUnexpectedMessage(char sender, OTMessage& m) {
  dbg(String("onUnexpectedMessage: sender=") + sender + ": " + m.toString());
  switch (sender) {
    case 'T': state.messages.unexpected.T++; return RC_UNEXP_T; // thermostat/master
    case 'B': state.messages.unexpected.B++; return RC_UNEXP_B; // boiler/ventilation/slave
    case 'R': state.messages.unexpected.R++; return RC_UNEXP_R; // otgw to thermostat
    case 'A': state.messages.unexpected.A++; return RC_UNEXP_A; // otgw to ventilation
  }
  return RC_UNEXP_O;
}

int toTemp(int8_t hi, int8_t lo) {
  // TODO: Need proof if temperatue conversion is correct for t<0
  // But wow? Even at winter time, temperature will never be <0 ... because of my setup.
  // Maybe someone else can help here?
  int sign = hi < 0 ?  -1 :  1;
  int abs  = hi < 0 ? -hi : hi;
  abs = 100 * abs + (100 * lo / 255);
  return sign * abs;
}
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
void loop() {

  // memory leak prevention: restart if free memory drops below 25% of initialy available
  if (health.initalFree < 0) {
    health.initalFree = ESP.getFreeHeap();
  } else {
    long freeNow = ESP.getFreeHeap();
    if ( (100 * freeNow) / health.initalFree < 25) {
#ifdef WITH_WEB_CALLS
      if (!health.rebootAnnounced) {
        String reason = String("Low memory ") + freeNow + " of " + health.initalFree + "B";
        sendAlert(String("μController rebooting: ") + reason, true, false);
        setRebootReason(reason);
      }
      health.rebootAnnounced = true;
#endif
      ESP.restart();
    }
  }

#ifdef WITH_DEBUG_UDP
  if (stopUdpLoggingAfter > 0 && millis() > stopUdpLoggingAfter) {
    dbg("*** UDP LOGGING STOPS ***");
    doLogUDP = false;
    stopUdpLoggingAfter = 0;
  }
#endif

  unsigned long now = millis();

  if (now > health.rebootTime) {
    if (!health.rebootAnnounced) {
      String reason = String("Uptime > ") + upTime();
      #ifdef WITH_WEB_CALLS
      sendAlert(String("μController rebooting: ") + reason, true, false);
      #endif
      setRebootReason(reason);
    }
    health.rebootAnnounced = true;
    ESP.reset(); // might fall through here?
  }

  #ifdef WITH_WEB_CALLS  
  if (now - lastConnectionSuccess > 60 * 60 * 1000) {
    if (!health.rebootAnnounced) {
      #ifdef WITH_WEB_CALLS      
      String reason = "No connectivity > 1h";
      sendAlert(String("μController rebooting: ") + reason, true, false);
      #endif
      setRebootReason(reason);
    }
    health.rebootAnnounced = true;
    ESP.reset(); // might fall through here?
  }
  #endif

  if (!health.startAnnounced) {

    health.startAnnounced = true;
    String reason = health.lastRebootDetails;
    String msg = String("μController started: reason: '") + reason + "', " + health.initalFree + " bytes free (" + buildNo + ")";
    dbg(msg);

    reason = "While in normal operation";
    setRebootReason(reason);
    dbg(String("new reason: ") + reason);

#ifdef WITH_WEB_CALLS
    sendAlert(msg, true, false);
#endif
  }

  if (state.ventOverride != state.ventAcknowledged) {
    unsigned long now = millis();
    if (health.ventDiffStarted == 0) {
      health.ventDiffStarted = now;
    }

    // allow the slave up to 30 seconds to accept/acknowledge a change of override value
    unsigned long delta = now - health.ventDiffStarted;
    if (delta > 60 * 1000) {

      health.isResponsive = false;

#ifdef WITH_WEB_CALLS
      delta = now - health.lastDiffReported;
      // report unresponsivness at most once per hour
      if (0 == health.lastDiffReported || delta > 3600 * 1000) {
        String msg;
        if (state.ventAcknowledged < 0) {
          msg = "Ventilation is not responding.";
        } else {
          msg = "Ventilation stopped responding.";
        }
        msg += " Please reset/replug the gateway!";
        sendAlert(msg, false, false);
        health.lastDiffReported = now;
      }
#endif

      // try to reset the OTGW, however at most once per 5 minutes
      delta = now - health.lastGWReset;
      if (delta > 5 * 60 * 1000) {
        resetOTGW();
        health.lastGWReset = now;

#ifdef WITH_WEB_CALLS
        // report at most once per hour
        delta = now - health.lastGWResetReported;
        if (0 == health.lastGWResetReported || delta > 3600 * 1000) {
          sendAlert("Tried to restart the OpenTherm Gateway", true, false);
          health.lastGWResetReported = now;
        }
#endif
      }
    }
  } else {
    health.ventDiffStarted = 0;
    health.isResponsive = true;
  }

  if (health.isResponsive && !health.wasResponsive) {
    unsigned long delta = millis() - health.lastRecoveryReported;
    if (delta > 5 * 60 * 1000) {
      #ifdef WITH_WEB_CALLS
      sendAlert("Ventilation recovered and seems to be responsive again.", false, false);
      #endif
      health.lastRecoveryReported = millis();
    }
  }

  //serialEvent();
  server.handleClient();
  #ifdef WITH_OTA
  ArduinoOTA.handle();
  #endif

#ifdef WITH_DALLAS_TEMP_SENSORS
  if (!temperaturesRequested || 0 == health.loopIterations % (500 * 1000))  {
    dbg("CALLING handleSensors()");
    handleSensors();
  }
#endif

  if (stringComplete) {
    //dbg(String("loop: stringComplete, inputString='") + inputString + "'"); 
    inputString.trim();
    state.lastMsg.serial = millis();
    state.messages.serial++;
    //String rc = 
    onOTGWMessage(inputString, true);
    //dbg(String("loop: onOTGWMessage: rc: ") + rc);    
    inputString = "";
    stringComplete = false;
  }

  handleHeartbeat();

#ifdef WITH_WEB_CALLS
  handleWebUpdate(false);
#endif

#ifdef ESP8266
  if (rebootScheduledAfterSetup > -1 && (unsigned long)rebootScheduledAfterSetup > millis()) {
    rebootScheduledAfterSetup = -1;
    dbgln("*********** REBOOT **********");
    delay(100);
    ESP.reset();
    delay(10000);
  }
#endif

  health.loopIterations++;
}


#ifdef WITH_DALLAS_TEMP_SENSORS
String toString(DeviceAddress& a) {
  String rtv;
  for (unsigned int i = 0; i < sizeof(a) / sizeof(a[0]); i++) {
    if (i) rtv += ":";
    if (a[i] < 0x10) rtv += "0";
    rtv += String(a[i], HEX);
  }
  return rtv;
}

/*
  // function to print a device's resolution
  void printResolution(DeviceAddress deviceAddress)
  {
  Serial.print("Resolution: ");
  Serial.print(sensors.getResolution(deviceAddress));
  Serial.println();
  }
*/

// function to print the temperature for a device
void printTemperature(DeviceAddress deviceAddress) {
  float tempC = sensors.getTempC(deviceAddress);
  dbg("Temp C: ");
  dbg(tempC);
}

void handleSensors() {

  //dbgln("handleSensors");
  if (!temperaturesRequested) {
    sensors.requestTemperatures();
    temperaturesRequested = true;
  }

  state.lastMeasure = millis();
  //dbgln("handleSensors: reading ts");
  for (int i = 0; i < state.sensorsFound; i++) {
    //dbg("sensors.getTempCByIndex("); dbg(i); dbgln(")");
    float t = sensors.getTempCByIndex(i);
    //dbg("t="); dbgln((int)(100*t));
    state.extraTemps[i] = 100 * t;
  }

  sensors.requestTemperatures();
  temperaturesRequested = true;
  //dbgln("handleSensors done");
}

void setupSensors() {
  //dbgln("setupSensors");

  // Start up the library
  sensors.begin();
  sensors.setResolution(11);

  // locate devices on the bus
  //dbg("locating devices...");
  state.sensorsFound = sensors.getDeviceCount();
  //dbg("found "); dbg(state.sensorsFound); dbgln(" sensors.");

  // report parasite power requirements
  //dbg("parasite power: ");
  //if (sensors.isParasitePowerMode()) dbgln("ON"); else dbgln("OFF");
}
#endif

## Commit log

2016-03-07 Renamed project. Added some logs. Added html files for browser based first time network setup.
    [configuration_memberid.txt, master_configuration.txt]
2016-03-07 Moved documentation from ino to README. Fixed typos.
    [ESP_VitoWifi.ino]
2016-03-07 First working version. Can set level and status looks ok although a bit buggy.
    [ESP_VitoWifi.ino]
2016-03-08 Added Fritzing schematics and PNG
    [VitoWifi.fzz]
2016-03-08 Added wiring diagram to README
2016-03-09 Fixed JS/ajax/css bugs in setup procedure
    [ESP_VitoWifi.ino]
2018-05-03 Fixed filterCheck status detection
    [ESP_VitoWifi.ino]
2018-11-19 Compiles for ESP32 now however untested. Added known TSPs (transparent slave parameters) to GUI
2023-01-13 Fixed: Loosing web connectivity after couple of days (force reboot after 1h)
    [ESP_VitoWifi.ino]
2023-01-16 Added comment regarding filter check
2023-01-19 Replaced web GET pu POST. Fixed bugs
    [ESP_VitoWifi.ino]
